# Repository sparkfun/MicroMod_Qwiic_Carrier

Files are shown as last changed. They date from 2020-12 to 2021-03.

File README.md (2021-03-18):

SparkFun MicroMod Qwiic Carrier Board
========================================

<table class="table table-hover table-striped table-bordered">
    <tr align="center">
      <td></td>
      <td></td>
    </tr>
    <tr align="center">
      <td><a href="https://www.sparkfun.com/products/17723">SparkFun Qwiic Carrier - Single</a></td>
      <td><a href="https://www.sparkfun.com/products/17724">SparkFun Qwiic Carrier - Double</a></td>
    </tr>
</table>

The MicroMod Qwiic Carrier Board for the [SparkFun MicroMod Ecosystem](https://www.sparkfun.com/micromod) can be used to rapidly prototype with other Qwiic devices. The MicroMod M.2 socket provides users the freedom to experiment with any processor board in the MicroMod ecosystem. This board also features two Qwiic connectors and 4-40 screw inserts to connect and mount Qwiic devices.

Repository Contents
-------------------
* **/Hardware** - Eagle design files (.brd, .sch)

Documentation
--------------
* **[Hookup Guide](https://learn.sparkfun.com/tutorials/1596)** - Basic hookup guide for the MicroMod Qwiic Carrier Board.

Product Versions
----------------
* [DEV-17723](https://www.sparkfun.com/products/17723) - Single
* [DEV-17724](https://www.sparkfun.com/products/17724) - Double

License Information
-------------------

This product is _**open source**_! 

Please review the LICENSE.md file for license information. 

If you have any questions or concerns on licensing, please contact technical support on our [SparkFun forums](https://forum.sparkfun.com/viewforum.php?f=152).

Distributed as-is; no warranty is given.

- Your friends at SparkFun.

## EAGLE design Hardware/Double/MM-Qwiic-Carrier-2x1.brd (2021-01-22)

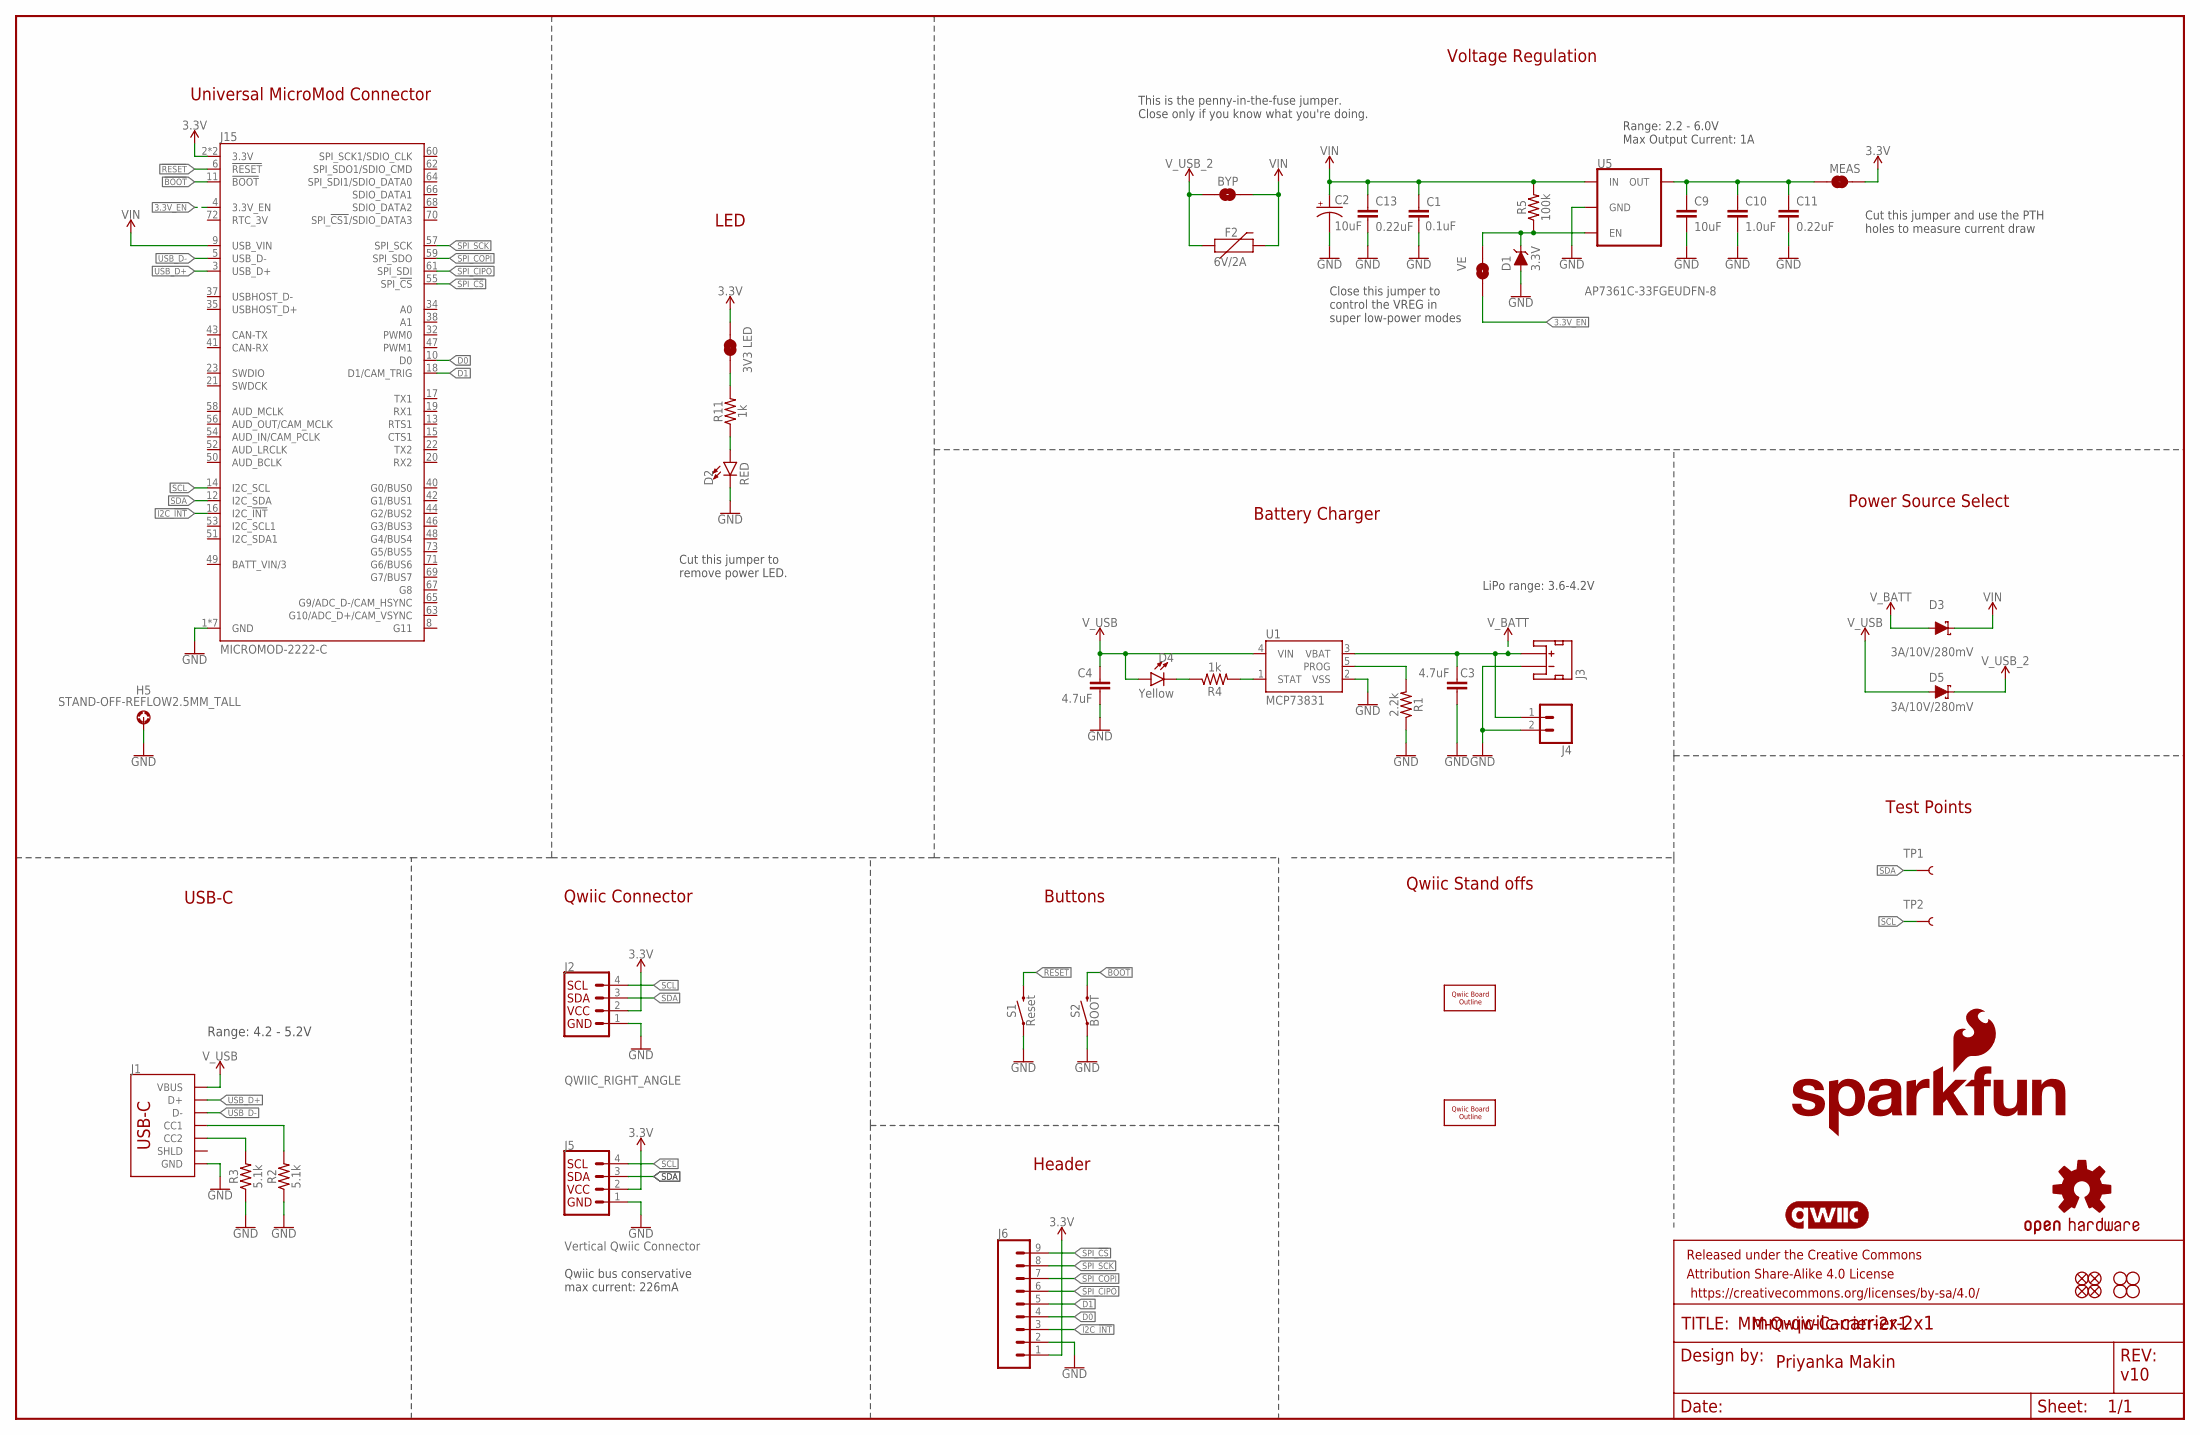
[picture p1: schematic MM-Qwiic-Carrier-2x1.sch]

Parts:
BYP: JUMPER-SMT_2_NO_SILK; SMT-JUMPER_2_NO_SILK
C1: 0.1uF; 0603
C2: 10uF; EIA3216
C3, C4: 4.7uF; 0603
C9: 10uF; 0603
C10: 1.0uF; 0603
C11, C13: 0.22uF; 0603
D1: 3.3V; SOD-323
D2: RED; LED-0603
D3, D5: 3A/10V/280mV; SOD-323
D4: Yellow; LED-0603
F2: 6V/2A; 1210
FD1, FD2, FD3, FD4: FIDUCIALUFIDUCIAL; FIDUCIAL-MICRO
FRAME1: FRAME-LEDGER; CREATIVE_COMMONS
H1, H2, H3, H4: STAND-OFF
H5: STAND-OFF-REFLOW2.5MM_TALL; STAND-OFF-REFLOW-M2.5
J1: USB_C_2-LAYER_PADS; USB-C-16P-2LAYER-PADS
J2: QWIIC_RIGHT_ANGLE; JST04_1MM_RA
J3: JST_2MM_MALE; JST-2-SMD
J4: CONN_021X02_NO_SILK; 1X02_NO_SILK
J5: Vertical Qwiic Connector; JST04_1MM_VERT
J6: CONN_09NO_SILK; 1X09_NO_SILK
J15: MICROMOD-2222-C; M.2-CONNECTOR-E
JP4: 3V3 LED; SMT-JUMPER_2_NC_TRACE_SILK
JP6: VE; SMT-JUMPER_2_NO_SILK
LOGO1: SFE_LOGO_NAME_FLAME.2_INCH; SFE_LOGO_NAME_FLAME_.2
LOGO2: QWIIC_LOGO_CONNECTOR; QWIIC_5.5MM
LOGO3: OSHW-LOGOM; OSHW-LOGO-M
MEAS: JUMPER-COMBO_2_NC_TRACE; COMBO-JUMPER_2_NC_TRACE
R1: 2.2k; 0603
R2, R3: 5.1k; 0603
R4, R11: 1k; 0603
R5: 100k; 0603
S1: Reset; TACTILE_SWITCH_SMD_5.2MM
S2: BOOT; TACTILE_SWITCH_SMD_5.2MM
TP1, TP2: TEST-POINT3X5; PAD.03X.05
U1: MCP73831; SOT23-5
U5: AP7361C-33FGEUDFN-8; UDFN-8
U$2, U$5: QWIIC_BOARD_OUTLINESTANDOFF; QWIIC_BOARD_MOUNT_SMD_STANDOFFS

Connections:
3.3V: J2.2, J5.2, J6.1, J15.2 (3.3V), J15.74 (3.3V), JP4.2, MEAS.2, MEAS.4 (2)
3.3V_EN: J15.4 (3.3V_EN), JP6.1
!BOOT!: J15.11 (!BOOT!), S2.3 (2), S2.4 (2)
!RESET!: J15.6 (!RESET!), S1.3 (2), S1.4 (2)
D0: J6.4, J15.10 (D0)
D1: J6.5, J15.18 (D1/CAM_TRIG)
GND: C1.2, C2.-, C3.2, C4.2, C9.2, C10.2, C11.2, C13.2, D1.A, D2.C, H5.1, J1.GND, J1.GND2 (GND), J2.1, J3.1 (-), J4.2, J5.1, J6.2, J15.1 (GND), J15.7 (GND), J15.33 (GND), J15.36 (GND), J15.39 (GND), J15.45 (GND), J15.75 (GND), R1.1, R2.1, R3.1, S1.1, S1.2 (1), S2.1, S2.2 (1), U1.2 (VSS), U5.4 (GND), U5.EP (GND)
I2C_!INT!: J6.3, J15.16 (I2C_!INT!)
unnamed: C9.1, C10.1, C11.1, MEAS.1, MEAS.3 (1), U5.1 (OUT)
unnamed: R1.2, U1.5 (PROG)
unnamed: D4.C, R4.1
unnamed: JP4.1, R11.2
unnamed: D2.A, R11.1
unnamed: R4.2, U1.1 (STAT)
unnamed: J1.A5 (CC1), R2.2
unnamed: J1.B5 (CC2), R3.2
SCL: J2.4, J5.4, J15.14 (I2C_SCL), TP2.P$1
SDA: J2.3, J5.3, J15.12 (I2C_SDA), TP1.P$1
SPI_!CS!: J6.9, J15.55 (SPI_!CS!)
SPI_CIPO: J6.6, J15.61 (SPI_SDI)
SPI_COPI: J6.7, J15.59 (SPI_SDO)
SPI_SCK: J6.8, J15.57 (SPI_SCK)
USB_D+: J1.A6 (D+), J1.B6 (D+), J15.3 (USB_D+)
USB_D-: J1.A7 (D-), J1.B7 (D-), J15.5 (USB_D-)
VIN: BYP.2, C1.1, C2.+, C13.1, D3.C, F2.2, J15.9 (USB_VIN), R5.2, U5.8 (IN)
VREG_EN: D1.C, JP6.2, R5.1, U5.5 (EN)
V_BATT: C3.1, D3.A, J3.2 (+), J4.1, U1.3 (VBAT)
V_USB: C4.1, D4.A, D5.A, J1.VBUS1 (VBUS), J1.VBUS2 (VBUS), U1.4 (VIN)
V_USB_2: BYP.1, D5.C, F2.1

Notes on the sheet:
USB-C
Universal MicroMod Connector
Priyanka Makin
MM-Qwiic-Carrier-2x1
LED
v10
Cut this jumper to remove power LED.
Range: 4.2 - 5.2V
Voltage Regulation
Range: 2.2 - 6.0V Max Output Current: 1A
Close this jumper to control the VREG in super low-power modes
This is the penny-in-the-fuse jumper. Close only if you know what you're doing.
Qwiic Connector
Buttons
Battery Charger
Qwiic Stand offs
Power Source Select
Test Points
Qwiic bus conservative max current: 226mA
Header
Cut this jumper and use the PTH holes to measure current draw
LiPo range: 3.6-4.2V

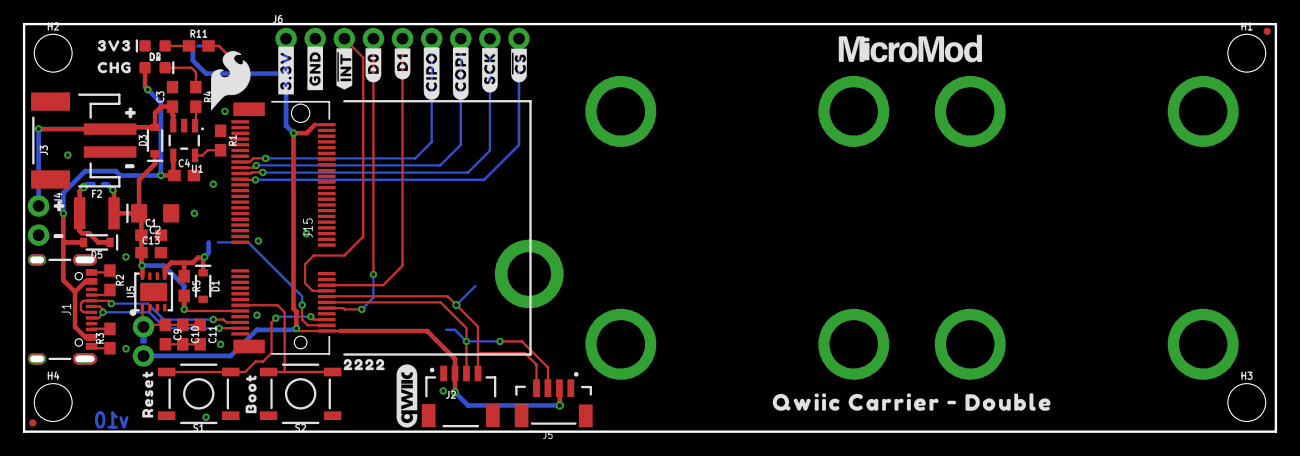
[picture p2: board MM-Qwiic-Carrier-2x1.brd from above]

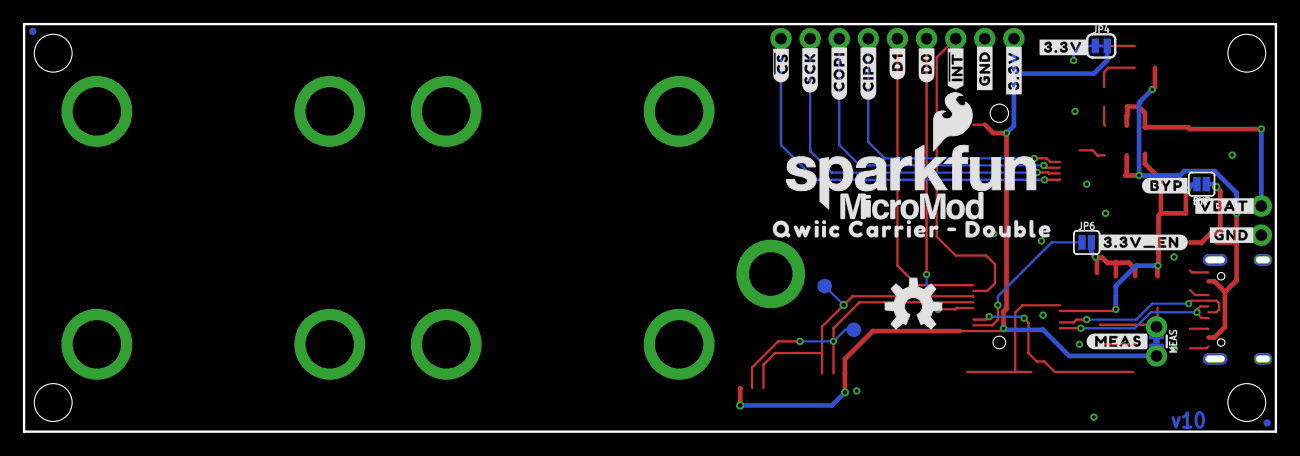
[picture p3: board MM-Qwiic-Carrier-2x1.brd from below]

Board: 2 copper layers, 109.2 x 35.6 mm, 90 parts (27 on the bottom side), 29 nets.

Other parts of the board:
U$1: #3#3V_EN#0
U$3: 3V30
U$4: CHG0
U$6, U$35, U$38: #3#3V#0
U$7: #BYP#0
U$8, U$14, U$33: #GND#0
U$9: #MEAS#0
U$10, U$13: QWIIC_CARRIER_#_DOUBLE0
U$11, U$32, U$36, U$37: #0
U$12: #VBAT#0
U$15, U$16: ##INT##0
U$17, U$18: #D0#0
U$20, U$21: #D1#0
U$22, U$23: #CIPO#0
U$24, U$25: #COPI#0
U$26, U$27: #SCK#0
U$28, U$29: ##CS##0
U$30: RESET0
U$31: BOOT0
U$34: 22220
U$44: SFE_LOGO_FLAME_.2
U$67, U$68: MICROMOD_LOGO_.5

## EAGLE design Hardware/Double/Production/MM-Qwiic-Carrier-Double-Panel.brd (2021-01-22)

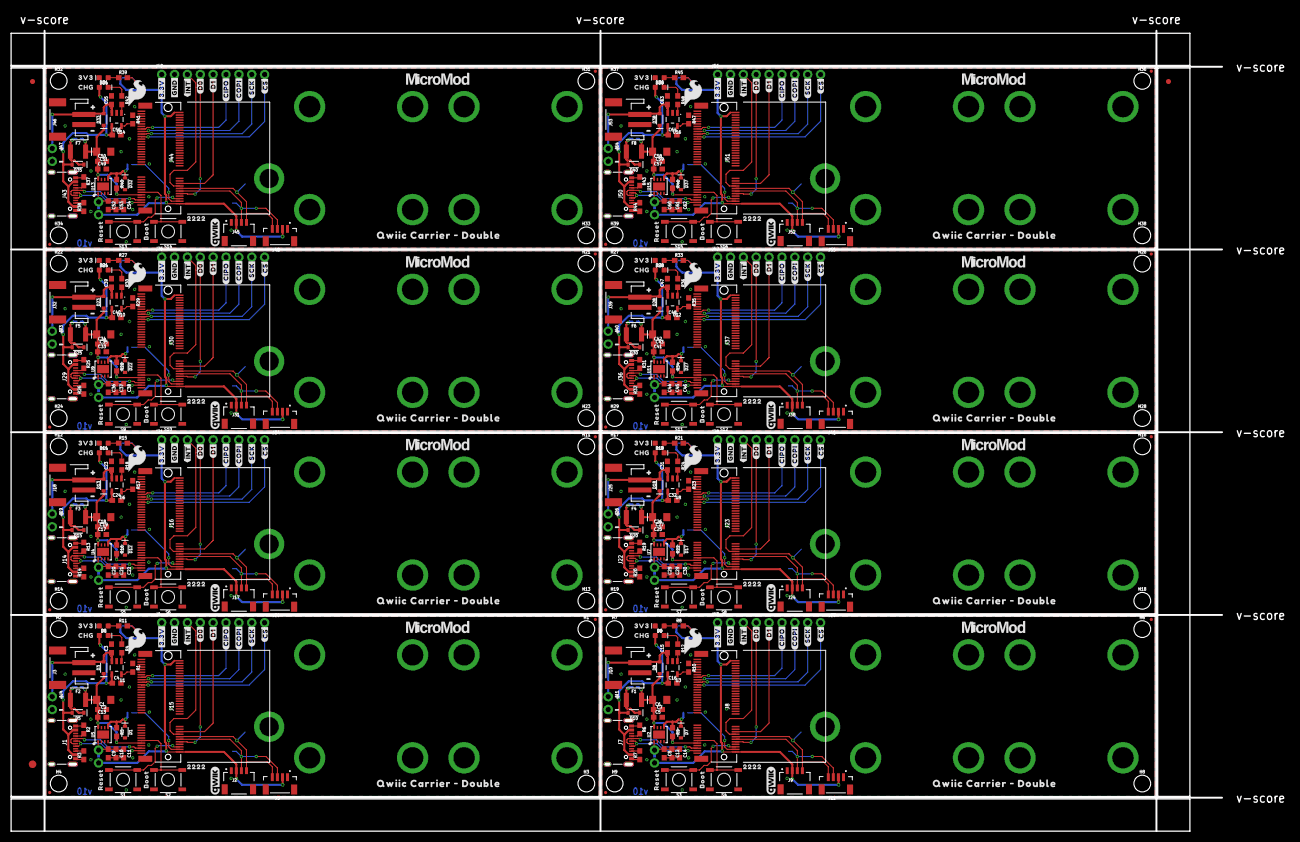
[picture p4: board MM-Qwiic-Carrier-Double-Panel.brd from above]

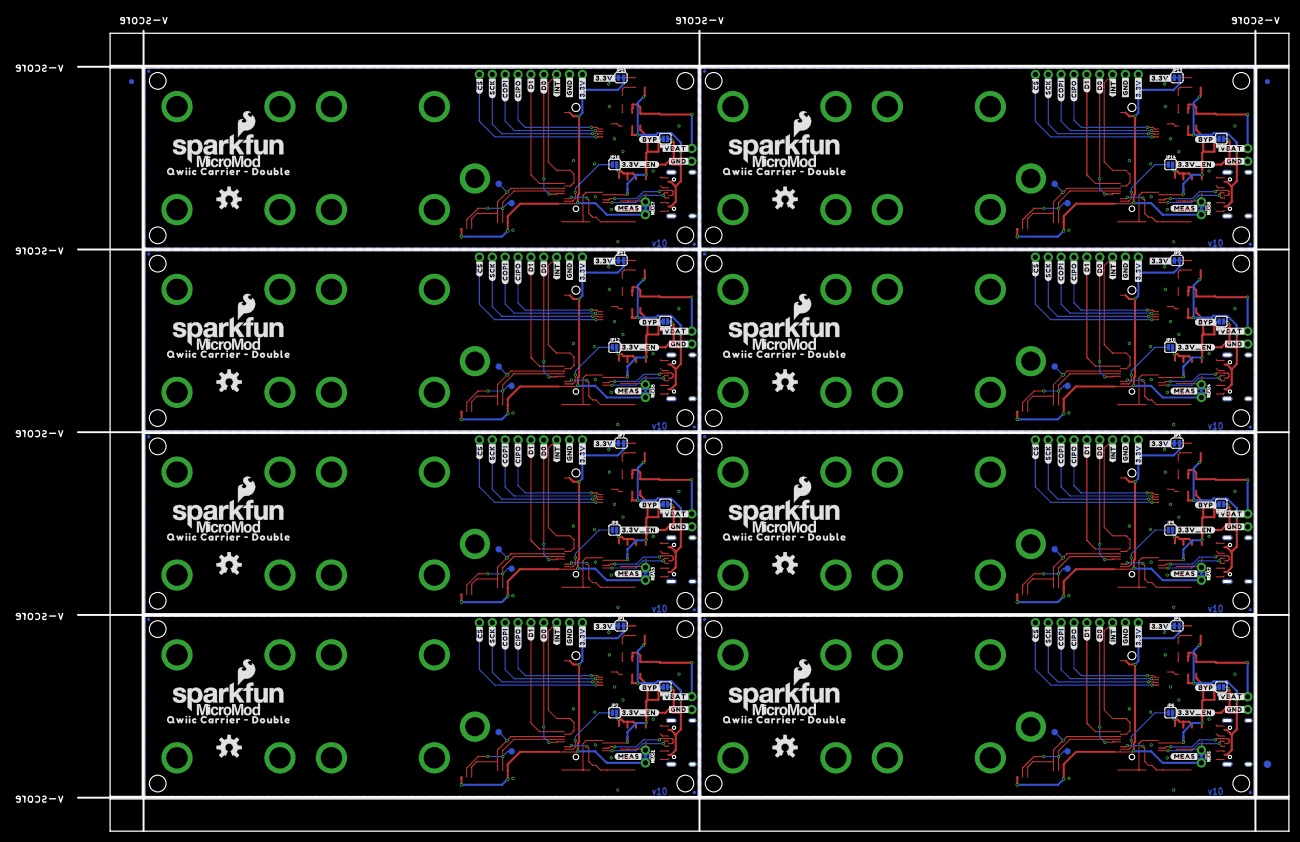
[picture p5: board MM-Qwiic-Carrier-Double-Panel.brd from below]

Board: 2 copper layers, 239.0 x 158.0 mm, 718 parts (219 on the bottom side), 232 nets.

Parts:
BYP, BYP1, BYP2, BYP3, BYP4, BYP5, BYP6, BYP7: JUMPER-SMT_2_NO_SILK; SMT-JUMPER_2_NO_SILK
C1, C6, C18, C26, C34, C42, C50, C58: 0.1uF; 0603
C2, C7, C19, C27, C35, C43, C51, C59: 10uF; EIA3216
C3, C4, C15, C16, C23, C24, C31, C32, C39, C40, C47, C48, C55, C56, C63, C64: 4.7uF; 0603
C5, C11, C13, C14, C17, C22, C25, C30, C33, C38, C41, C46, C49, C54, C57, C62: 0.22uF; 0603
C8, C9, C20, C28, C36, C44, C52, C60: 10uF; 0603
C10, C12, C21, C29, C37, C45, C53, C61: 1.0uF; 0603
D1, D7, D12, D17, D22, D27, D32, D37: 3.3V; SOD-323
D2, D6, D11, D16, D21, D26, D31, D36: RED; LED-0603
D3, D5, D8, D10, D13, D15, D18, D20, D23, D25, D28, D30, D33, D35, D38, D40: 3A/10V/280mV; SOD-323
D4, D9, D14, D19, D24, D29, D34, D39: Yellow; LED-0603
E$1, E$2, E$3, E$4: FIDUCIAL-1X2
E$5, E$6: FIDUCIAL-1.5X3
F1, F2, F3, F4, F5, F6, F7, F8: 6V/2A; 1210
FD1, FD2, FD3, FD4, FD5, FD6, FD7, FD8, FD9, FD10, FD11, FD12, FD13, FD14, FD15, FD16, FD17, FD18, FD19, FD20, FD21, FD22, FD23, FD24, FD25, FD26, FD27, FD28, FD29, FD30, FD31, FD32: FIDUCIALUFIDUCIAL; FIDUCIAL-MICRO
H1, H2, H3, H4, H6, H7, H8, H9, H11, H12, H13, H14, H16, H17, H18, H19, H21, H22, H23, H24, H26, H27, H28, H29, H31, H32, H33, H34, H36, H37, H38, H39: STAND-OFF
H5, H10, H15, H20, H25, H30, H35, H40: STAND-OFF-REFLOW2.5MM_TALL; STAND-OFF-REFLOW-M2.5
J1, J7, J14, J22, J29, J36, J43, J50: USB-C-16P-2LAYER-PADS
J2, J9, J17, J24, J31, J38, J45, J52: QWIIC_RIGHT_ANGLE; JST04_1MM_RA
J3, J10, J18, J25, J32, J39, J46, J53: JST-2-SMD
J4, J11, J19, J26, J33, J40, J47, J54: 1X02_NO_SILK
J5, J12, J20, J27, J34, J41, J48, J55: Vertical Qwiic Connector; JST04_1MM_VERT
J6, J13, J21, J28, J35, J42, J49, J56: 1X09_NO_SILK
J8, J15, J16, J23, J30, J37, J44, J51: MICROMOD-2222-C; M.2-CONNECTOR-E
JP1, JP3, JP4, JP7, JP9, JP11, JP13, JP15: 3V3 LED; SMT-JUMPER_2_NC_TRACE_SILK
JP2, JP5, JP6, JP8, JP10, JP12, JP14, JP16: VE; SMT-JUMPER_2_NO_SILK
LOGO1, LOGO6, LOGO9, LOGO12, LOGO15, LOGO18, LOGO21, LOGO24: SFE_LOGO_NAME_FLAME.2_INCH; SFE_LOGO_NAME_FLAME_.2
LOGO2, LOGO4, LOGO7, LOGO10, LOGO13, LOGO16, LOGO19, LOGO22: QWIIC_LOGO_CONNECTOR; QWIIC_5.5MM
LOGO3, LOGO5, LOGO8, LOGO11, LOGO14, LOGO17, LOGO20, LOGO23: OSHW-LOGOM; OSHW-LOGO-M
MEAS, MEAS1, MEAS2, MEAS3, MEAS4, MEAS5, MEAS6, MEAS7: COMBO-JUMPER_2_NC_TRACE
R1, R10, R17, R23, R29, R35, R41, R47: 2.2k; 0603
R2, R3, R6, R7, R13, R14, R19, R20, R25, R26, R31, R32, R37, R38, R43, R44: 5.1k; 0603
R4, R8, R11, R12, R15, R18, R21, R24, R27, R30, R33, R36, R39, R42, R45, R48: 1k; 0603
R5, R9, R16, R22, R28, R34, R40, R46: 100k; 0603
S1, S3, S5, S7, S9, S11, S13, S15: Reset; TACTILE_SWITCH_SMD_5.2MM
S2, S4, S6, S8, S10, S12, S14, S16: BOOT; TACTILE_SWITCH_SMD_5.2MM
TP1, TP2, TP3, TP4, TP5, TP6, TP7, TP8, TP9, TP10, TP11, TP12, TP13, TP14, TP15, TP16: TEST-POINT3X5; PAD.03X.05
U1, U3, U6, U8, U10, U12, U14, U16: MCP73831; SOT23-5
U2, U4, U5, U7, U9, U11, U13, U15: AP7361C-33FGEUDFN-8; UDFN-8
U$1, U$48, U$90, U$130, U$170, U$210, U$250, U$290: #3#3V_EN#0
U$2, U$5, U$46, U$78, U$88, U$118, U$128, U$158, U$168, U$198, U$208, U$238, U$248, U$278, U$288, U$318: QWIIC_BOARD_OUTLINESTANDOFF; QWIIC_BOARD_MOUNT_SMD_STANDOFFS
U$3, U$47, U$89, U$129, U$169, U$209, U$249, U$289: 3V30
U$4, U$41, U$84, U$124, U$164, U$204, U$244, U$284: CHG0
U$6, U$35, U$38, U$42, U$72, U$73, U$85, U$112, U$113, U$125, U$152, U$153, U$165, U$192, U$193, U$205, U$232, U$233, U$245, U$272, U$273, U$285, U$312, U$313: #3#3V#0
U$7, U$43, U$86, U$126, U$166, U$206, U$246, U$286: #BYP#0
U$8, U$14, U$33, U$49, U$50, U$58, U$91, U$92, U$100, U$131, U$132, U$140, U$171, U$172, U$180, U$211, U$212, U$220, U$251, U$252, U$260, U$291, U$292, U$300: #GND#0
U$9, U$45, U$87, U$127, U$167, U$207, U$247, U$287: #MEAS#0
U$10, U$13, U$79, U$80, U$119, U$120, U$159, U$160, U$199, U$200, U$239, U$240, U$279, U$280, U$319, U$320: QWIIC_CARRIER_#_DOUBLE0
U$11, U$32, U$36, U$37, U$59, U$60, U$61, U$62, U$101, U$102, U$103, U$104, U$141, U$142, U$143, U$144, U$181, U$182, U$183, U$184, U$221, U$222, U$223, U$224, U$261, U$262, U$263, U$264, U$301, U$302, U$303, U$304: #0
U$12, U$57, U$99, U$139, U$179, U$219, U$259, U$299: #VBAT#0
U$15, U$16, U$76, U$77, U$116, U$117, U$156, U$157, U$196, U$197, U$236, U$237, U$276, U$277, U$316, U$317: ##INT##0
U$17, U$18, U$63, U$64, U$105, U$106, U$145, U$146, U$185, U$186, U$225, U$226, U$265, U$266, U$305, U$306: #D0#0
U$19, U$44, U$81, U$121, U$161, U$201, U$241, U$281: SFE_LOGO_FLAME_.2
U$20, U$21, U$65, U$66, U$107, U$108, U$147, U$148, U$187, U$188, U$227, U$228, U$267, U$268, U$307, U$308: #D1#0
U$22, U$23, U$51, U$52, U$93, U$94, U$133, U$134, U$173, U$174, U$213, U$214, U$253, U$254, U$293, U$294: #CIPO#0
U$24, U$25, U$53, U$54, U$95, U$96, U$135, U$136, U$175, U$176, U$215, U$216, U$255, U$256, U$295, U$296: #COPI#0
U$26, U$27, U$55, U$56, U$97, U$98, U$137, U$138, U$177, U$178, U$217, U$218, U$257, U$258, U$297, U$298: #SCK#0
U$28, U$29, U$74, U$75, U$114, U$115, U$154, U$155, U$194, U$195, U$234, U$235, U$274, U$275, U$314, U$315: ##CS##0
U$30, U$69, U$109, U$149, U$189, U$229, U$269, U$309: RESET0
U$31, U$70, U$110, U$150, U$190, U$230, U$270, U$310: BOOT0
U$34, U$71, U$111, U$151, U$191, U$231, U$271, U$311: 22220
U$39, U$40, U$67, U$68, U$82, U$83, U$122, U$123, U$162, U$163, U$202, U$203, U$242, U$243, U$282, U$283: MICROMOD_LOGO_.5

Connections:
3.3V: J2.2, J5.2, J6.1, J15.2, J15.74, JP4.2, MEAS.2, MEAS.4
3.3V1: J8.2, J8.74, J9.2, J12.2, J13.1, JP1.2, MEAS1.2, MEAS1.4
3.3V2: J16.2, J16.74, J17.2, J20.2, J21.1, JP3.2, MEAS2.2, MEAS2.4
3.3V3: J23.2, J23.74, J24.2, J27.2, J28.1, JP7.2, MEAS3.2, MEAS3.4
3.3V4: J30.2, J30.74, J31.2, J34.2, J35.1, JP9.2, MEAS4.2, MEAS4.4
3.3V5: J37.2, J37.74, J38.2, J41.2, J42.1, JP11.2, MEAS5.2, MEAS5.4
3.3V6: J44.2, J44.74, J45.2, J48.2, J49.1, JP13.2, MEAS6.2, MEAS6.4
3.3V7: J51.2, J51.74, J52.2, J55.2, J56.1, JP15.2, MEAS7.2, MEAS7.4
3.3V_EN: J15.4, JP6.1
3.3V_EN1: J8.4, JP2.1
3.3V_EN2: J16.4, JP5.1
3.3V_EN3: J23.4, JP8.1
3.3V_EN4: J30.4, JP10.1
3.3V_EN5: J37.4, JP12.1
3.3V_EN6: J44.4, JP14.1
3.3V_EN7: J51.4, JP16.1
!BOOT!: J15.11, S2.3, S2.4
!BOOT!1: J8.11, S4.3, S4.4
!BOOT!2: J16.11, S6.3, S6.4
!BOOT!3: J23.11, S8.3, S8.4
!BOOT!4: J30.11, S10.3, S10.4
!BOOT!5: J37.11, S12.3, S12.4
!BOOT!6: J44.11, S14.3, S14.4
!BOOT!7: J51.11, S16.3, S16.4
!RESET!: J15.6, S1.3, S1.4
!RESET!1: J8.6, S3.3, S3.4
!RESET!2: J16.6, S5.3, S5.4
!RESET!3: J23.6, S7.3, S7.4
!RESET!4: J30.6, S9.3, S9.4
!RESET!5: J37.6, S11.3, S11.4
!RESET!6: J44.6, S13.3, S13.4
!RESET!7: J51.6, S15.3, S15.4
D0: J6.4, J15.10
D1: J6.5, J15.18
D2: J8.10, J13.4
D3: J8.18, J13.5
D4: J16.10, J21.4
D5: J16.18, J21.5
D6: J23.10, J28.4
D7: J23.18, J28.5
D8: J30.10, J35.4
D9: J30.18, J35.5
D10: J37.10, J42.4
D11: J37.18, J42.5
D12: J44.10, J49.4
D13: J44.18, J49.5
D14: J51.10, J56.4
D15: J51.18, J56.5
GND: C1.2, C2.-, C3.2, C4.2, C9.2, C10.2, C11.2, C13.2, D1.A, D2.C, H5.1, J1.GND, J1.GND2, J2.1, J3.1, J4.2, J5.1, J6.2, J15.1, J15.7, J15.33, J15.36, J15.39, J15.45, J15.75, R1.1, R2.1, R3.1, S1.1, S1.2, S2.1, S2.2, U1.2, U5.4, U5.EP
GND1: C5.2, C6.2, C7.-, C8.2, C12.2, C14.2, C15.2, C16.2, D6.C, D7.A, H10.1, J7.GND, J7.GND2, J8.1, J8.7, J8.33, J8.36, J8.39, J8.45, J8.75, J9.1, J10.1, J11.2, J12.1, J13.2, R6.1, R7.1, R10.1, S3.1, S3.2, S4.1, S4.2, U2.4, U2.EP, U3.2
GND2: C17.2, C18.2, C19.-, C20.2, C21.2, C22.2, C23.2, C24.2, D11.C, D12.A, H15.1, J14.GND, J14.GND2, J16.1, J16.7, J16.33, J16.36, J16.39, J16.45, J16.75, J17.1, J18.1, J19.2, J20.1, J21.2, R13.1, R14.1, R17.1, S5.1, S5.2, S6.1, S6.2, U4.4, U4.EP, U6.2
GND3: C25.2, C26.2, C27.-, C28.2, C29.2, C30.2, C31.2, C32.2, D16.C, D17.A, H20.1, J22.GND, J22.GND2, J23.1, J23.7, J23.33, J23.36, J23.39, J23.45, J23.75, J24.1, J25.1, J26.2, J27.1, J28.2, R19.1, R20.1, R23.1, S7.1, S7.2, S8.1, S8.2, U7.4, U7.EP, U8.2
GND4: C33.2, C34.2, C35.-, C36.2, C37.2, C38.2, C39.2, C40.2, D21.C, D22.A, H25.1, J29.GND, J29.GND2, J30.1, J30.7, J30.33, J30.36, J30.39, J30.45, J30.75, J31.1, J32.1, J33.2, J34.1, J35.2, R25.1, R26.1, R29.1, S9.1, S9.2, S10.1, S10.2, U9.4, U9.EP, U10.2
GND5: C41.2, C42.2, C43.-, C44.2, C45.2, C46.2, C47.2, C48.2, D26.C, D27.A, H30.1, J36.GND, J36.GND2, J37.1, J37.7, J37.33, J37.36, J37.39, J37.45, J37.75, J38.1, J39.1, J40.2, J41.1, J42.2, R31.1, R32.1, R35.1, S11.1, S11.2, S12.1, S12.2, U11.4, U11.EP, U12.2
GND6: C49.2, C50.2, C51.-, C52.2, C53.2, C54.2, C55.2, C56.2, D31.C, D32.A, H35.1, J43.GND, J43.GND2, J44.1, J44.7, J44.33, J44.36, J44.39, J44.45, J44.75, J45.1, J46.1, J47.2, J48.1, J49.2, R37.1, R38.1, R41.1, S13.1, S13.2, S14.1, S14.2, U13.4, U13.EP, U14.2
GND7: C57.2, C58.2, C59.-, C60.2, C61.2, C62.2, C63.2, C64.2, D36.C, D37.A, H40.1, J50.GND, J50.GND2, J51.1, J51.7, J51.33, J51.36, J51.39, J51.45, J51.75, J52.1, J53.1, J54.2, J55.1, J56.2, R43.1, R44.1, R47.1, S15.1, S15.2, S16.1, S16.2, U15.4, U15.EP, U16.2
I2C_!INT!: J6.3, J15.16
I2C_!INT!1: J8.16, J13.3
I2C_!INT!2: J16.16, J21.3
I2C_!INT!3: J23.16, J28.3
I2C_!INT!4: J30.16, J35.3
I2C_!INT!5: J37.16, J42.3
I2C_!INT!6: J44.16, J49.3
I2C_!INT!7: J51.16, J56.3
unnamed: C9.1, C10.1, C11.1, MEAS.1, MEAS.3, U5.1
unnamed: R1.2, U1.5
unnamed: D4.C, R4.1
unnamed: JP4.1, R11.2
unnamed: J7.A5, R6.2
unnamed: D2.A, R11.1
unnamed: J7.B5, R7.2
unnamed: R4.2, U1.1
unnamed: JP1.1, R8.2
unnamed: J1.A5, R2.2
unnamed: J1.B5, R3.2
unnamed: D6.A, R8.1
unnamed: C8.1, C12.1, C14.1, MEAS1.1, MEAS1.3, U2.1
unnamed: R10.2, U3.5
unnamed: D9.C, R12.1
unnamed: R12.2, U3.1
unnamed: J14.A5, R13.2
unnamed: J14.B5, R14.2
unnamed: JP3.1, R15.2
unnamed: D11.A, R15.1
unnamed: C20.1, C21.1, C22.1, MEAS2.1, MEAS2.3, U4.1
unnamed: R17.2, U6.5
unnamed: D14.C, R18.1
unnamed: R18.2, U6.1
unnamed: J22.A5, R19.2
unnamed: J22.B5, R20.2
unnamed: JP7.1, R21.2
unnamed: D16.A, R21.1
unnamed: C28.1, C29.1, C30.1, MEAS3.1, MEAS3.3, U7.1
unnamed: R23.2, U8.5
unnamed: D19.C, R24.1
unnamed: R24.2, U8.1
unnamed: J29.A5, R25.2
unnamed: J29.B5, R26.2
unnamed: JP9.1, R27.2
unnamed: D21.A, R27.1
unnamed: C36.1, C37.1, C38.1, MEAS4.1, MEAS4.3, U9.1
unnamed: R29.2, U10.5
unnamed: D24.C, R30.1
unnamed: R30.2, U10.1
unnamed: J36.A5, R31.2
unnamed: J36.B5, R32.2
unnamed: JP11.1, R33.2
unnamed: D26.A, R33.1
unnamed: C44.1, C45.1, C46.1, MEAS5.1, MEAS5.3, U11.1
unnamed: R35.2, U12.5
unnamed: D29.C, R36.1
unnamed: R36.2, U12.1
unnamed: J43.A5, R37.2
unnamed: J43.B5, R38.2
unnamed: JP13.1, R39.2
unnamed: D31.A, R39.1
unnamed: C52.1, C53.1, C54.1, MEAS6.1, MEAS6.3, U13.1
unnamed: R41.2, U14.5
unnamed: D34.C, R42.1
unnamed: R42.2, U14.1
unnamed: J50.A5, R43.2
unnamed: J50.B5, R44.2
unnamed: JP15.1, R45.2
unnamed: D36.A, R45.1
unnamed: C60.1, C61.1, C62.1, MEAS7.1, MEAS7.3, U15.1
unnamed: R47.2, U16.5
unnamed: D39.C, R48.1
unnamed: R48.2, U16.1
SCL: J2.4, J5.4, J15.14, TP2.P$1
SCL1: J8.14, J9.4, J12.4, TP4.P$1
SCL2: J16.14, J17.4, J20.4, TP6.P$1
SCL3: J23.14, J24.4, J27.4, TP8.P$1
SCL4: J30.14, J31.4, J34.4, TP10.P$1
SCL5: J37.14, J38.4, J41.4, TP12.P$1
SCL6: J44.14, J45.4, J48.4, TP14.P$1
SCL7: J51.14, J52.4, J55.4, TP16.P$1
SDA: J2.3, J5.3, J15.12, TP1.P$1
SDA1: J8.12, J9.3, J12.3, TP3.P$1
SDA2: J16.12, J17.3, J20.3, TP5.P$1
SDA3: J23.12, J24.3, J27.3, TP7.P$1
SDA4: J30.12, J31.3, J34.3, TP9.P$1
SDA5: J37.12, J38.3, J41.3, TP11.P$1
SDA6: J44.12, J45.3, J48.3, TP13.P$1
SDA7: J51.12, J52.3, J55.3, TP15.P$1
SPI_!CS!: J6.9, J15.55
SPI_!CS!1: J8.55, J13.9
SPI_!CS!2: J16.55, J21.9
SPI_!CS!3: J23.55, J28.9
SPI_!CS!4: J30.55, J35.9
SPI_!CS!5: J37.55, J42.9
SPI_!CS!6: J44.55, J49.9
SPI_!CS!7: J51.55, J56.9
SPI_CIPO: J6.6, J15.61
SPI_CIPO1: J8.61, J13.6
SPI_CIPO2: J16.61, J21.6
SPI_CIPO3: J23.61, J28.6
SPI_CIPO4: J30.61, J35.6
SPI_CIPO5: J37.61, J42.6
SPI_CIPO6: J44.61, J49.6
SPI_CIPO7: J51.61, J56.6
SPI_COPI: J6.7, J15.59
SPI_COPI1: J8.59, J13.7
SPI_COPI2: J16.59, J21.7
SPI_COPI3: J23.59, J28.7
SPI_COPI4: J30.59, J35.7
SPI_COPI5: J37.59, J42.7
SPI_COPI6: J44.59, J49.7
SPI_COPI7: J51.59, J56.7
SPI_SCK: J6.8, J15.57
SPI_SCK1: J8.57, J13.8
SPI_SCK2: J16.57, J21.8
SPI_SCK3: J23.57, J28.8
SPI_SCK4: J30.57, J35.8
SPI_SCK5: J37.57, J42.8
SPI_SCK6: J44.57, J49.8
SPI_SCK7: J51.57, J56.8
USB_D+: J1.A6, J1.B6, J15.3
USB_D+1: J7.A6, J7.B6, J8.3
USB_D+2: J14.A6, J14.B6, J16.3
USB_D+3: J22.A6, J22.B6, J23.3
USB_D+4: J29.A6, J29.B6, J30.3
USB_D+5: J36.A6, J36.B6, J37.3
USB_D+6: J43.A6, J43.B6, J44.3
USB_D+7: J50.A6, J50.B6, J51.3
USB_D-: J1.A7, J1.B7, J15.5
USB_D-1: J7.A7, J7.B7, J8.5
USB_D-2: J14.A7, J14.B7, J16.5
USB_D-3: J22.A7, J22.B7, J23.5
USB_D-4: J29.A7, J29.B7, J30.5
USB_D-5: J36.A7, J36.B7, J37.5
USB_D-6: J43.A7, J43.B7, J44.5
USB_D-7: J50.A7, J50.B7, J51.5
VIN: BYP.2, C1.1, C2.+, C13.1, D3.C, F2.2, J15.9, R5.2, U5.8
VIN1: BYP1.2, C5.1, C6.1, C7.+, D8.C, F1.2, J8.9, R9.2, U2.8
VIN2: BYP2.2, C17.1, C18.1, C19.+, D13.C, F3.2, J16.9, R16.2, U4.8
VIN3: BYP3.2, C25.1, C26.1, C27.+, D18.C, F4.2, J23.9, R22.2, U7.8
VIN4: BYP4.2, C33.1, C34.1, C35.+, D23.C, F5.2, J30.9, R28.2, U9.8
VIN5: BYP5.2, C41.1, C42.1, C43.+, D28.C, F6.2, J37.9, R34.2, U11.8
VIN6: BYP6.2, C49.1, C50.1, C51.+, D33.C, F7.2, J44.9, R40.2, U13.8
VIN7: BYP7.2, C57.1, C58.1, C59.+, D38.C, F8.2, J51.9, R46.2, U15.8
VREG_EN: D1.C, JP6.2, R5.1, U5.5
VREG_EN1: D7.C, JP2.2, R9.1, U2.5
VREG_EN2: D12.C, JP5.2, R16.1, U4.5
VREG_EN3: D17.C, JP8.2, R22.1, U7.5
VREG_EN4: D22.C, JP10.2, R28.1, U9.5
VREG_EN5: D27.C, JP12.2, R34.1, U11.5
VREG_EN6: D32.C, JP14.2, R40.1, U13.5
VREG_EN7: D37.C, JP16.2, R46.1, U15.5
V_BATT: C3.1, D3.A, J3.2, J4.1, U1.3
V_BATT1: C15.1, D8.A, J10.2, J11.1, U3.3
V_BATT2: C23.1, D13.A, J18.2, J19.1, U6.3
V_BATT3: C31.1, D18.A, J25.2, J26.1, U8.3
V_BATT4: C39.1, D23.A, J32.2, J33.1, U10.3
V_BATT5: C47.1, D28.A, J39.2, J40.1, U12.3
V_BATT6: C55.1, D33.A, J46.2, J47.1, U14.3
V_BATT7: C63.1, D38.A, J53.2, J54.1, U16.3
V_USB: C4.1, D4.A, D5.A, J1.VBUS1, J1.VBUS2, U1.4
V_USB1: C16.1, D9.A, D10.A, J7.VBUS1, J7.VBUS2, U3.4
V_USB2: C24.1, D14.A, D15.A, J14.VBUS1, J14.VBUS2, U6.4
V_USB3: C32.1, D19.A, D20.A, J22.VBUS1, J22.VBUS2, U8.4
V_USB4: C40.1, D24.A, D25.A, J29.VBUS1, J29.VBUS2, U10.4
V_USB5: C48.1, D29.A, D30.A, J36.VBUS1, J36.VBUS2, U12.4
V_USB6: C56.1, D34.A, D35.A, J43.VBUS1, J43.VBUS2, U14.4
V_USB7: C64.1, D39.A, D40.A, J50.VBUS1, J50.VBUS2, U16.4
V_USB_1: BYP1.1, D10.C, F1.1
V_USB_2: BYP.1, D5.C, F2.1
V_USB_3: BYP2.1, D15.C, F3.1
V_USB_4: BYP3.1, D20.C, F4.1
V_USB_5: BYP4.1, D25.C, F5.1
V_USB_6: BYP5.1, D30.C, F6.1
V_USB_7: BYP6.1, D35.C, F7.1
V_USB_8: BYP7.1, D40.C, F8.1

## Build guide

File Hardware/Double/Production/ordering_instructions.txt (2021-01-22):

panel size, 233x158mm
PCB thickness, 1.6mm
number of layers, 2
soldermask color, Red
silkscreen color, White
oz copper, 1oz
finish, HASL lead free
stencils, top
pcs per panel, 8
min trace width, 0.2032mm / 0.0080in
min drill size, 0.3048mm / 0.0120in

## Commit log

2020-11-30 Create Eagle files
    [MM-Qwiic-Snap.brd, MM-Qwiic-Snap.sch]
2020-11-30 Preliminary schematic done?
    [MM-Qwiic-Snap.brd, MM-Qwiic-Snap.sch]
2020-12-01 Board layout
    [MM-Qwiic-Snap.brd, MM-Qwiic-Snap.sch]
2020-12-02 Created part for stand off, proto layout finished
    [MM-Qwiic-Snap.brd, MM-Qwiic-Snap.sch]
2020-12-02 Switch out stand offs
    [MM-Qwiic-Snap.brd, MM-Qwiic-Snap.sch]
2020-12-03 Create 2x1 version and generate production files
    [MM-Qwiic-Snap-1x1-Panel.GBL, MM-Qwiic-Snap-1x1-Panel.GBO, MM-Qwiic-Snap-1x1-Panel.GBP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]
2020-12-03 Renamed from qwiic snap to qwiic carrier
    [MM-Qwiic-Carrier-1x1.brd, MM-Qwiic-Carrier-1x1.sch, MM-Qwiic-Carrier-2x1.brd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]
2020-12-07 Remove production files. Design review changes
    [MM-Qwiic-Carrier-1x1.brd, MM-Qwiic-Carrier-1x1.sch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]
2020-12-08 Fix silk screen
    [MM-Qwiic-Carrier-1x1.brd, MM-Qwiic-Carrier-1x1.sch, MM-Qwiic-Carrier-2x1.brd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]
2020-12-08 Review before ordering
    [MM-Qwiic-Carrier-1x1.brd, MM-Qwiic-Carrier-1x1.sch]
2020-12-09 silk screen
    [MM-Qwiic-Carrier-1x1.brd, MM-Qwiic-Carrier-2x1.brd, MM-Qwiic-Carrier-2x1.sch]
2020-12-10 Update measures on 2x1
    [MM-Qwiic-Carrier-2x1.brd]
2020-12-10 Silk screen changes
    [MM-Qwiic-Carrier-1x1.brd, MM-Qwiic-Carrier-2x1.brd]
2020-12-11 QC Feedback
    [MM-Qwiic-Carrier-1x1.brd, MM-Qwiic-Carrier-2x1.brd]
2020-12-15 Generate CAM files
    [MM-Qwiic-Carrier-1x1.GBL, MM-Qwiic-Carrier-1x1.GBO, MM-Qwiic-Carrier-1x1.GBP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]
2021-01-18 Update tcream for 4-40 standoffs
    [MM-Qwiic-Carrier-1x1.brd, MM-Qwiic-Carrier-1x1.sch, MM-Qwiic-Carrier-2x1.brd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]
2021-01-18 Run of engineering checklist
    [MM-Qwiic-Carrier-1x1.brd, MM-Qwiic-Carrier-1x1.sch, MM-Qwiic-Carrier-2x1.brd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]
2021-01-19 Changes from design review
    [MM-Qwiic-Carrier-1x1.brd, MM-Qwiic-Carrier-1x1.sch]
2021-01-20 Add dimensions to 2x1
    [MM-Qwiic-Carrier-2x1.brd]
2021-01-21 Silk changes from red board design review
    [MM-Qwiic-Carrier-1x1.brd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]
2021-01-21 Remove redundant production files
    Accidentally tried to panelize a panel
    [MM-Qwiic-Carrier-2x1-Panel-Panel.brd]
2021-01-21 Move SF logo, board name silk screen on bottom
    Renamed eagle files from 1x1, 2x1 to single, double
    Cleaned up library files
    [MM-Qwiic-Carrier-Double.brd, MM-Qwiic-Carrier-Double.sch, MM-Qwiic-Carrier-Single.brd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]
2021-01-22 Panelized both 1x1 and 2x1
    [MM-Qwiic-Carrier-1x1-Panel.GBL, MM-Qwiic-Carrier-1x1-Panel.GBO, MM-Qwiic-Carrier-1x1-Panel.GBP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]
2021-01-22 Renaming
    1x1 --> Single
    2x1 --> Double
    Re-panelized
    [MM-Qwiic-Carrier-1x1-Panel.GBL, MM-Qwiic-Carrier-1x1-Panel.GBO, MM-Qwiic-Carrier-1x1-Panel.GBP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]
2021-01-22 Re-panelized with corrected position silk screen
    This is the last time I've got to re-panel hopefully!
    [MM-Qwiic-Carrier-1x1-Panel.GBO, MM-Qwiic-Carrier-1x1.GBL, MM-Qwiic-Carrier-1x1.GBO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]

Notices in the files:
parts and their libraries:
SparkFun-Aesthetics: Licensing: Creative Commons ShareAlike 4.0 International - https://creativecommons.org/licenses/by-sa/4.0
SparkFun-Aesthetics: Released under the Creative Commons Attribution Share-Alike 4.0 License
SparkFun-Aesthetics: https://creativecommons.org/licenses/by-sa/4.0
